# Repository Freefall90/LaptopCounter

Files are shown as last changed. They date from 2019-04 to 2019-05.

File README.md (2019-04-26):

# LaptopCounter
An "accident counter" LED clock for a coworker who regularly leaves his laptop at home

We have this guy at work who will leave his computer at home pretty regularly. We got to joking about needing one of those LED "days since last accident" displays in the office. So I set about to create one.

It will count up to 999 days, can be manually set by rotating the dial, and reset by pushing the dial.

Oh yeah, the code and circuitry depends on having this LED clock screen I salvaged with some really weird common anode setup. So, it's probably not all that reusable. Sorry.

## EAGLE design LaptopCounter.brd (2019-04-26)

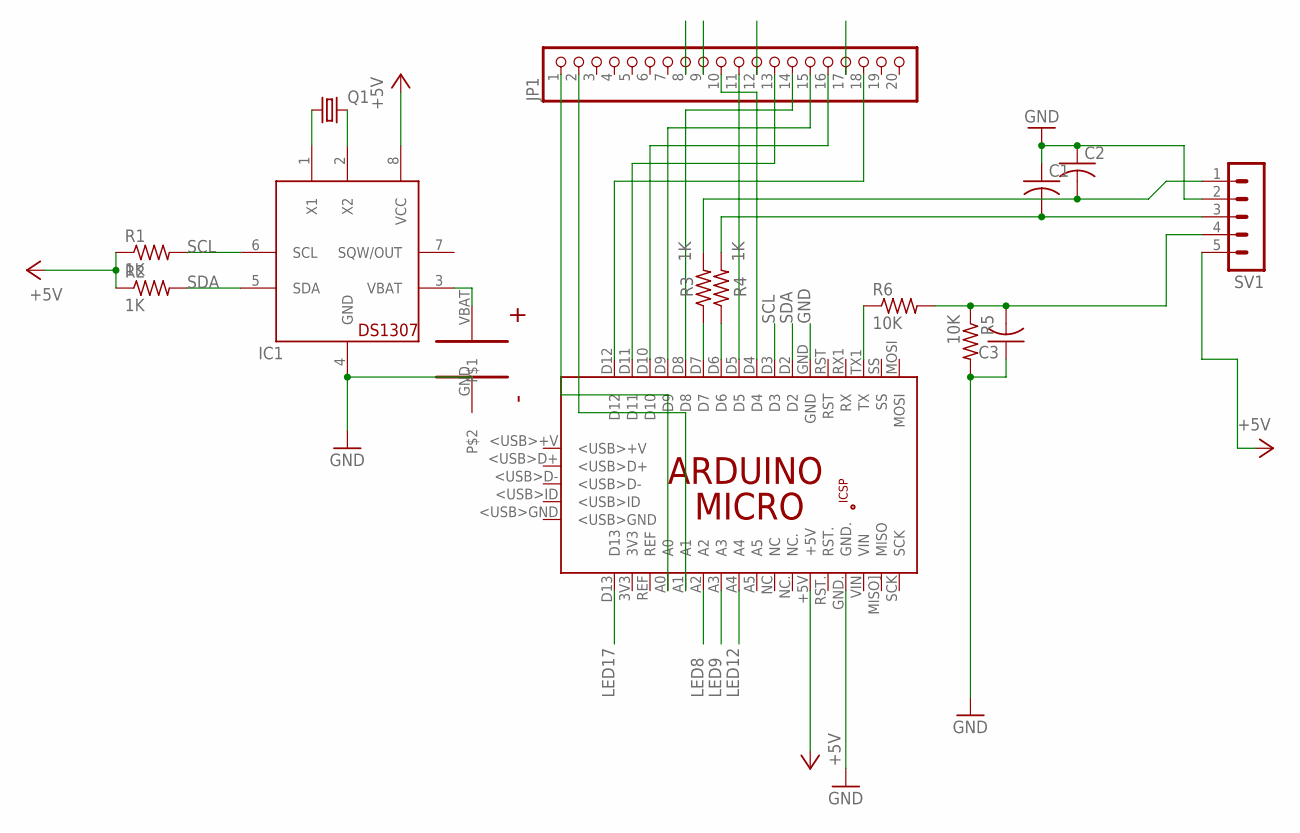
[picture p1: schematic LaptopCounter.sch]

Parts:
C1, C2, C3: C-US025-024X044; C025-024X044
IC1: DS1307; DIL08
JP1: PINHD-1X20; 1X20
PCB1: ARDUINO_MICRO
Q1: CRYSTALTC26H; TC26H
R1, R2, R3, R4: 1K; 0207/10
R5, R6: 10K; 0207/10
SV1: MA05-1
U$1: CR2032; 2PIN_TH

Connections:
+5V: IC1.8 (VCC), PCB1.+5V, R1.1, R2.1, SV1.5
GND: C1.1, C2.1, C3.1, IC1.4 (GND), PCB1.GND, PCB1.GND., R5.2, SV1.2, U$1.GND
LED8: JP1.8, PCB1.A2
LED9: JP1.9, PCB1.A3
LED12: JP1.12, PCB1.A4
LED17: JP1.17, PCB1.D13
unnamed: IC1.1 (X1), Q1.1
unnamed: IC1.2 (X2), Q1.2
unnamed: PCB1.D6, R4.1
unnamed: PCB1.D7, R3.1
unnamed: C1.2, R4.2, SV1.3
unnamed: C2.2, R3.2, SV1.1
unnamed: JP1.18, PCB1.D12
unnamed: JP1.13, PCB1.D11
unnamed: JP1.16, PCB1.D10
unnamed: JP1.15, PCB1.D9
unnamed: JP1.14, PCB1.D8
unnamed: JP1.11, PCB1.D5
unnamed: JP1.10, PCB1.D4
unnamed: PCB1.TX1 (TX), R6.1
unnamed: C3.2, R5.1, R6.2, SV1.4
unnamed: JP1.1, PCB1.A0
unnamed: JP1.2, PCB1.A1
unnamed: IC1.3 (VBAT), U$1.VBAT
SCL: IC1.6 (SCL), PCB1.D3, R1.2
SDA: IC1.5 (SDA), PCB1.D2, R2.2

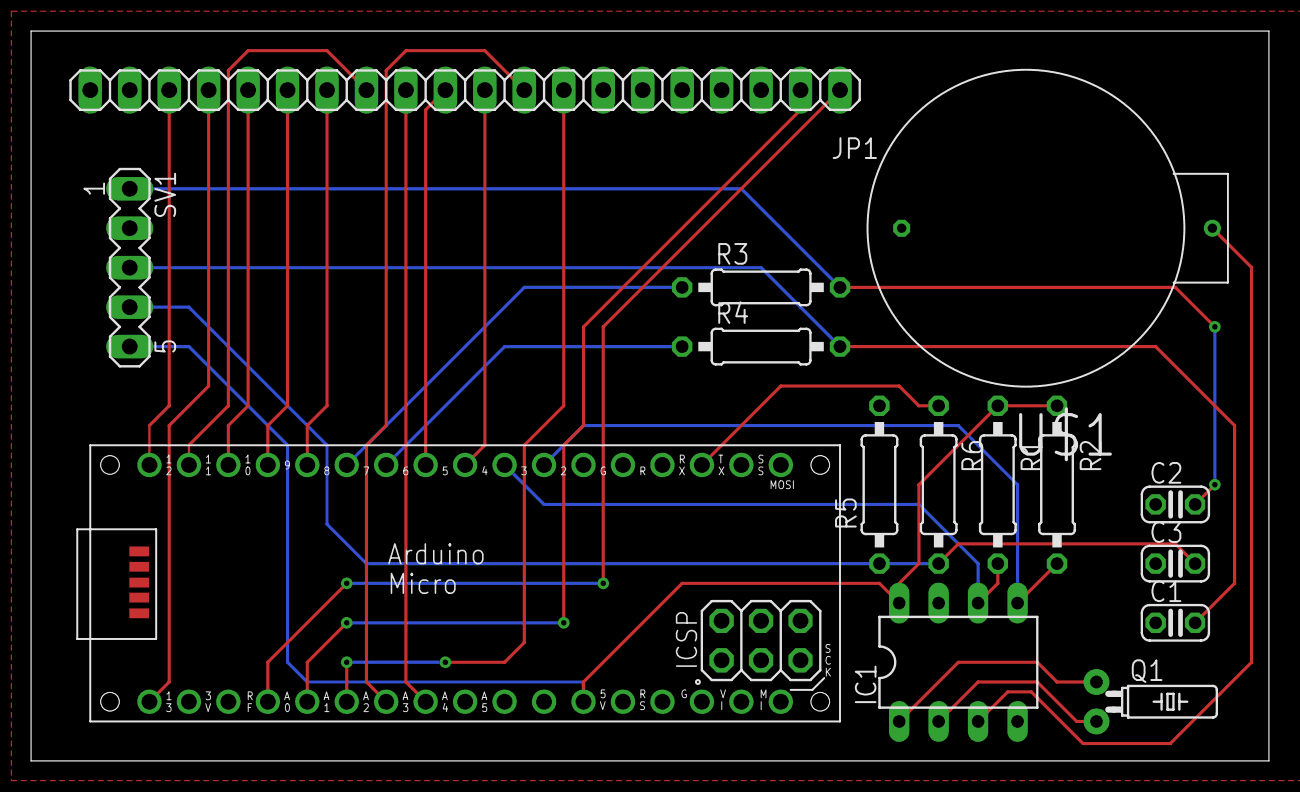
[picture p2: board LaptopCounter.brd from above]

Board: 2 copper layers, 79.7 x 47.0 mm, 15 parts (0 on the bottom side), 26 nets.

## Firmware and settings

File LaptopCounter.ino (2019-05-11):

#include <Encoder.h>

#include <Time.h>
#include <TimeLib.h>

#include <DS1307RTC.h>
#include <Wire.h>

#define TOP_ROW A0
#define BOT_ROW A1

//#define DIG1A 11 //led pin 7
#define DIG2L A2 //led pin 8
#define DIG2R A3 //led pin 9
#define DIG2TB 4 //led pin 10
#define DIG2M 5 //led pin 11
#define DIG3L A4 //led pin 12
#define DIG3R 11 //led pin 13
#define DIG3TB 8 //led pin 14
#define DIG34M 9 //led pin 15
#define DIG4L 10 //led pin 16
#define DIG4R 13 //led pin 17
#define DIG4TB 12 //led pin 18
#define buttonPin 1

const byte DIG1[] = {};
const byte DIG2[] = {DIG2L, DIG2R, DIG2TB, DIG2M};
const byte DIG3[] = {DIG3L, DIG3R, DIG3TB, DIG34M};
const byte DIG4[] = {DIG4L, DIG4R, DIG4TB, DIG34M};
const byte rows[2] = {TOP_ROW, BOT_ROW};

Encoder dial(7, 6);
tmElements_t tm;

const char *monthName[12] = {
  "Jan", "Feb", "Mar", "Apr", "May", "Jun",
  "Jul", "Aug", "Sep", "Oct", "Nov", "Dec"
};
bool parse=false;
bool config=false;

//Order of segments is as follows:
//In most cases, the middle segment should be specified twice (stupid LED configuration in my particular clock)
//Also, it's common anode, so 0 is on and 1 is off
//         3
//      ------
//     |      |
//  1  |   4  | 2
//     |------|
//     |   8  |
//   5 |      | 6
//      ------
//         7

/*
const int zero[] =  {0, 0, 0, 1, 0, 0, 0, 1};
const int one[] =   {1, 0, 1, 1, 1, 0, 1, 1};
const int two[] =   {1, 0, 0, 0, 0, 1, 0, 0};
const int three[] = {1, 0, 0, 0, 1, 0, 0, 0};
const int four[] =  {0, 0, 1, 0, 1, 0, 1, 0};
const int five[] =  {0, 1, 0, 0, 1, 0, 0, 1};
const int six[] =   {0, 1, 0, 1, 0, 0, 0, 0};
const int seven[] = {1, 0, 0, 1, 1, 0, 1, 1};
const int eight[] = {0, 0, 0, 0, 0, 0, 0, 0};
const int nine[] =  {0, 0, 0, 0, 1, 0, 1, 0};
*/

const int numberArray[10][8] = {  {0, 0, 0, 1, 0, 0, 0, 1}, //zero
                                  {1, 0, 1, 1, 1, 0, 1, 1}, //one
                                  {1, 0, 0, 0, 0, 1, 0, 0}, //two
                                  {1, 0, 0, 0, 1, 0, 0, 0}, //three
                                  {0, 0, 1, 0, 1, 0, 1, 0}, //four
                                  {0, 1, 0, 0, 1, 0, 0, 0}, //five
                                  {0, 1, 0, 0, 0, 0, 0, 0}, //six
                                  {1, 0, 0, 1, 1, 0, 1, 1}, //seven
                                  {0, 0, 0, 0, 0, 0, 0, 0}, //eight
                                  {0, 0, 0, 0, 1, 0, 1, 0} }; //nine

const int errorArray[2][8] = {    {0, 1, 0, 0, 0, 1, 0, 0}, //"E"
                                  {1, 1, 1, 0, 0, 1, 1, 0}}; //"r"

//This is basically a hack to use a number indexed array for displaying "Err"
const int errorValues[3] = {1, 1, 0};

int dayCount;
int today;
int yesterday;
bool resetDay = false;

void setup()
{
  // Set all used pins to OUTPUT
  // This is very important! If the pins are set to input
  // the display will be very dim.

  pinMode(DIG1, OUTPUT);
  pinMode(DIG2L, OUTPUT);
  pinMode(DIG2R, OUTPUT);
  pinMode(DIG2TB, OUTPUT);
  pinMode(DIG2M, OUTPUT);
  pinMode(DIG3L, OUTPUT);
  pinMode(DIG3R, OUTPUT);
  pinMode(DIG3TB, OUTPUT);
  pinMode(DIG34M, OUTPUT);
  pinMode(DIG4L, OUTPUT);
  pinMode(DIG4R, OUTPUT);
  pinMode(DIG4TB, OUTPUT);

  pinMode(buttonPin, INPUT);

  pinMode(TOP_ROW, OUTPUT);
  pinMode(BOT_ROW, OUTPUT);

  // Open serial port
  Serial.begin(9600);

  //while (!Serial) ; // wait until Arduino Serial Monitor opens
  setSyncProvider(RTC.get);   // the function to get the time from the RTC
  if(timeStatus()!= timeSet)
  {
    setTime();
    Serial.println("Didn't have time from RTC. Setting...");
  }
  else
  {
    config = true;
    Serial.println("Time synced with RTC");
    Serial.println(config);
  //  dayCount
  }
  if(!config)
  {
    Serial.println("Error: Cannot set time");
    dayCount = 100; //force drawing all 3 digits
    while(true)
    {
      drawRow(errorValues, errorArray);
    }
  }



  today = day();
  yesterday = day() - 1;
  resetDay = false;
}

long positionDial = -999;
int buttonState = 0;

void loop()
{
  if (timeStatus() != timeSet)
  {
    Serial.println("The time has not been set.  Please run the Time");
    Serial.println("TimeRTCSet example, or DS1307RTC SetTime example.");
    Serial.println();
    while (true)
    {
      drawRow(errorValues, errorArray);
      delay(1000);
      turnAllOff();
      delay(500);
    }
  }

//Reset the day count when someone hits the button
  buttonState = digitalRead(buttonPin);
  if(buttonState == HIGH)
  {
    resetDay = true;
  }

  if(resetDay)
  {
    dayCount = 0;
    resetDay = false;
  }


  //Set up button and dial functionality
  long newPos = dial.read();
  if(newPos - 3 >  positionDial || newPos + 3 < positionDial)
  {
    Serial.print("Dial = ");
    Serial.println(newPos);

    if(newPos > positionDial + 3){dayCount++;}
    if(newPos < positionDial - 3){dayCount--;}

    positionDial = newPos;
  }

  //Check to see if we've advanced a day, and if so, update 'yesterday'
  //today = day();
  //Test with minutes
  today = second();

  if(today != yesterday + 1)
  {
    dayCount++;
    yesterday = today - 1;
    Serial.print("Incremented to ");
    Serial.println(dayCount);
  }


//TURNING OFF FOR NOW - THIS IS WHAT DISPLAYS THE NUMBER
  drawNumber(dayCount); //testing

}

void drawNumber(int wholeNumber)
{
  int original = wholeNumber;
  int values[3];
  //int thousands = 0;
  int hundreds = 0;
  int tens = 0;
  int ones = 0;

  //Figure out the value of each place
  for(int i = 0; i < 3; i++)
  {
    values[i] = wholeNumber % 10;
    wholeNumber /= 10;
  }

  drawRow(values, numberArray);

}

//Drawing a row of LEDs at once
//This helps with brightness by lighting up
//multiple LEDs at once, rather than one at a time.
void drawRow(int valueArray[], int charArray[][8])
{
  //Basically, we're going to loop through the values array and set all the
  //LEDs for each bit
  for(int i = 0; i < 8; i++)
  {
    if(i != 3)
    {
      if(dayCount > 99)
        digitalWrite(DIG2[i % 4], charArray[valueArray[2]][i]);
      if(dayCount > 9)
        digitalWrite(DIG3[i % 4], charArray[valueArray[1]][i]);
    }
    if(i != 7)
      digitalWrite(DIG4[i % 4], charArray[valueArray[0]][i]);

    if(i < 4)
    {
      digitalWrite(TOP_ROW, HIGH);
      digitalWrite(BOT_ROW, LOW);
    }
    else
    {
      digitalWrite(TOP_ROW, LOW);
      digitalWrite(BOT_ROW, HIGH);
    }
  //  Serial.print("Loop: ");
  //  Serial.println(i);
  //  Serial.print("Segment value: ");
  //  Serial.println(numberArray[1][i]);
    //delay(500);
    if(i % 4 == 3)
    {
      delay(2);
      //delayMicroseconds(500);
      turnAllOff();
    }
  }
}

void turnAllOff()
{
  digitalWrite(TOP_ROW, LOW);
  digitalWrite(BOT_ROW, LOW);

  digitalWrite(DIG1, HIGH);
  digitalWrite(DIG2L, HIGH);
  digitalWrite(DIG2R, HIGH);
  digitalWrite(DIG2TB, HIGH);
  digitalWrite(DIG2M, HIGH);
  digitalWrite(DIG3L, HIGH);
  digitalWrite(DIG3R, HIGH);
  digitalWrite(DIG3TB, HIGH);
  digitalWrite(DIG34M, HIGH);
  digitalWrite(DIG4L, HIGH);
  digitalWrite(DIG4R, HIGH);
  digitalWrite(DIG4TB, HIGH);
}

bool getTime(const char *str)
{
  int Hour, Min, Sec;

  if (sscanf(str, "%d:%d:%d", &Hour, &Min, &Sec) != 3) return false;
  tm.Hour = Hour;
  tm.Minute = Min;
  tm.Second = Sec;
  return true;
}

bool getDate(const char *str)
{
  char Month[12];
  int Day, Year;
  uint8_t monthIndex;

  if (sscanf(str, "%s %d %d", Month, &Day, &Year) != 3) return false;
  for (monthIndex = 0; monthIndex < 12; monthIndex++) {
    if (strcmp(Month, monthName[monthIndex]) == 0) break;
  }
  if (monthIndex >= 12) return false;
  tm.Day = Day;
  tm.Month = monthIndex + 1;
  tm.Year = CalendarYrToTm(Year);
  return true;
}

void setTime()
{
  if (getDate(__DATE__) && getTime(__TIME__))
  {
    parse = true;
    // and configure the RTC with this info
    if (RTC.write(tm))
    {
      config = true;
    }
  }
}

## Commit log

2019-04-26 Initial commit.
    [LaptopCounter.brd, LaptopCounter.sch]
2019-04-26 Removing board history
2019-05-06 Initial stab at per-row LED light up
2019-05-11 Brightness fixed. Time setting fixed. Battery not required!
    [LaptopCounter.ino]
